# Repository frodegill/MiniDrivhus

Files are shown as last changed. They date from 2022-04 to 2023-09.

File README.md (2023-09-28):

## about project

Minidrivhus (english: indoor greenhouse) started as a dedicated system for pre-cultivating seeds indoors. It was based on ESP8266 and a custom shield that could support up to 3 soil sensors 3 water pumps and sensors for temperature, humidity and light intensity. There was also a relay for controlling an external grow light, and I've made custom PCBs for small and medium-sized indoor grow lights.  
With all this in place, I also started to make an outdoor greenhouse. When it was completed I expanded the project to also support outdoor greenhouse, which meant I had to add a relay to turn on and off a fan, sensors for outdoor temperature and humidity, a relay for operating a valve controlling water flow to an intermediate water reservoir, sensors for low and high level of water in this reservoir and voltage sensor for the solar panel charged 12V car battery that would power the whole system.  
Unfortunately, the first set of soil sensors did not handle humid/wet environment very well and the second (waterproof) soil sensor had a very limited value range, so I have now started redoing the whole system where the sensors are connected by RS-485 and the water pumps are controlled by a 16-channel multiplexer so one system can control up to 15 plants (having one channel act as an Off channel). To control this I needed more GPIO pins than the ESP8266 provided, so the new system will be based on an ESP32. Stay tuned for new and improved PCBs and source code!

## pictures

The original indoor greenhouse, ready for pre-cultivating seeds:  
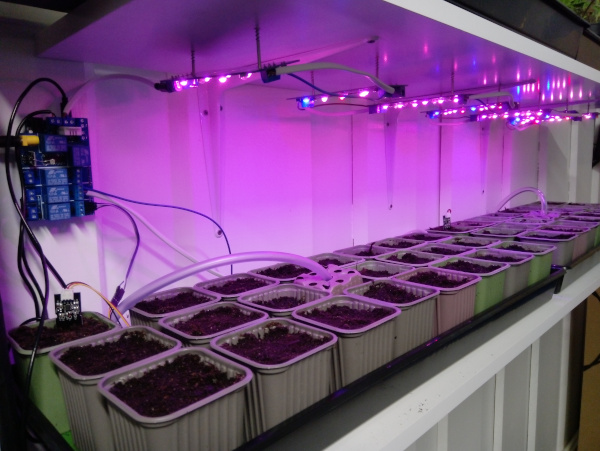
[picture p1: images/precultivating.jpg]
Minidrivhus setup


Setup for the outdoor greenhouse. 3 systems, each controlling 3 water pumps, for a total of 9 buckets for plants. There is also a small controller for the main water valve and a solar charge controller  
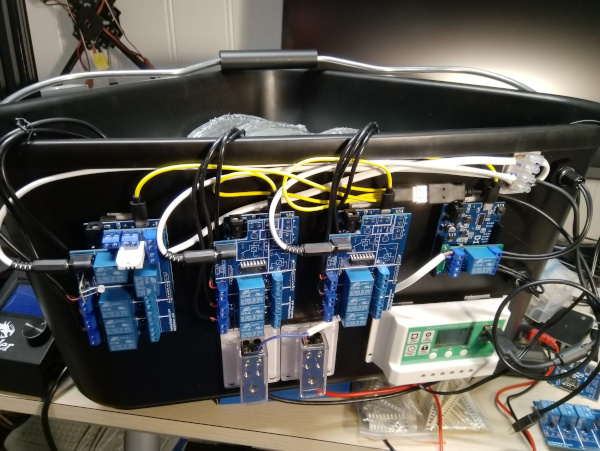
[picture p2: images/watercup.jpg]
watercup


I have 3 x 210 liter buckets for collecting rain water. The water is gravity-fed into an intermediate bucket in a corner of the greenhouse. All water pumps are located in this bucket. There are low- and high water level sensors that are used to control when a water valve is opened and water flows down from the 3 large buckets.  
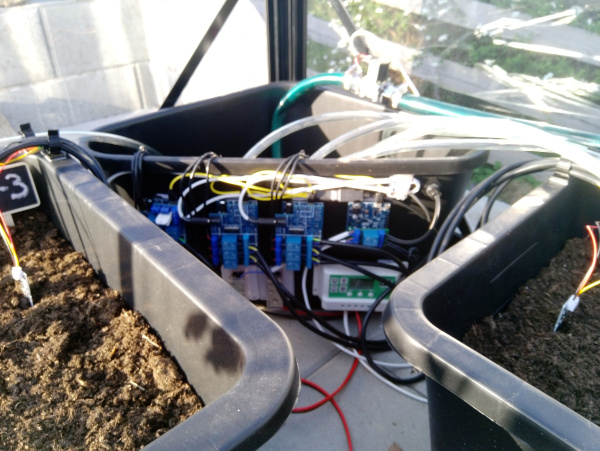
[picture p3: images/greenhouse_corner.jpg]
watercup in corner of greenhouse


A complete setup looks like this:  
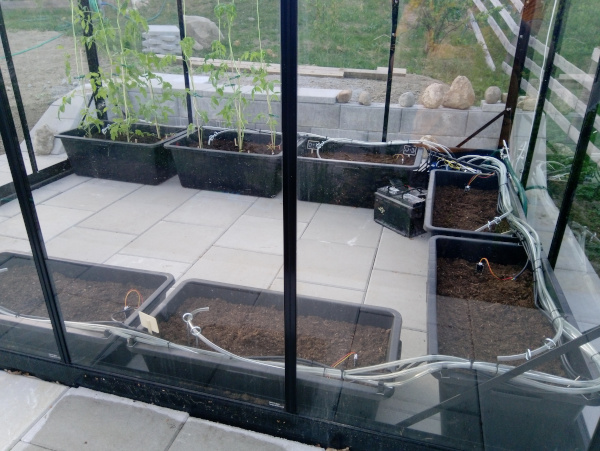
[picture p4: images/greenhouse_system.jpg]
greenhouse ready


..and after automatically watering plants all summer, it looks like this:  
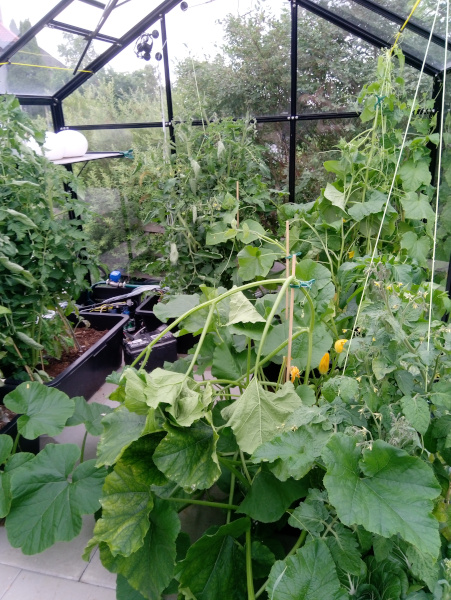
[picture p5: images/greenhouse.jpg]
greenhouse with plants


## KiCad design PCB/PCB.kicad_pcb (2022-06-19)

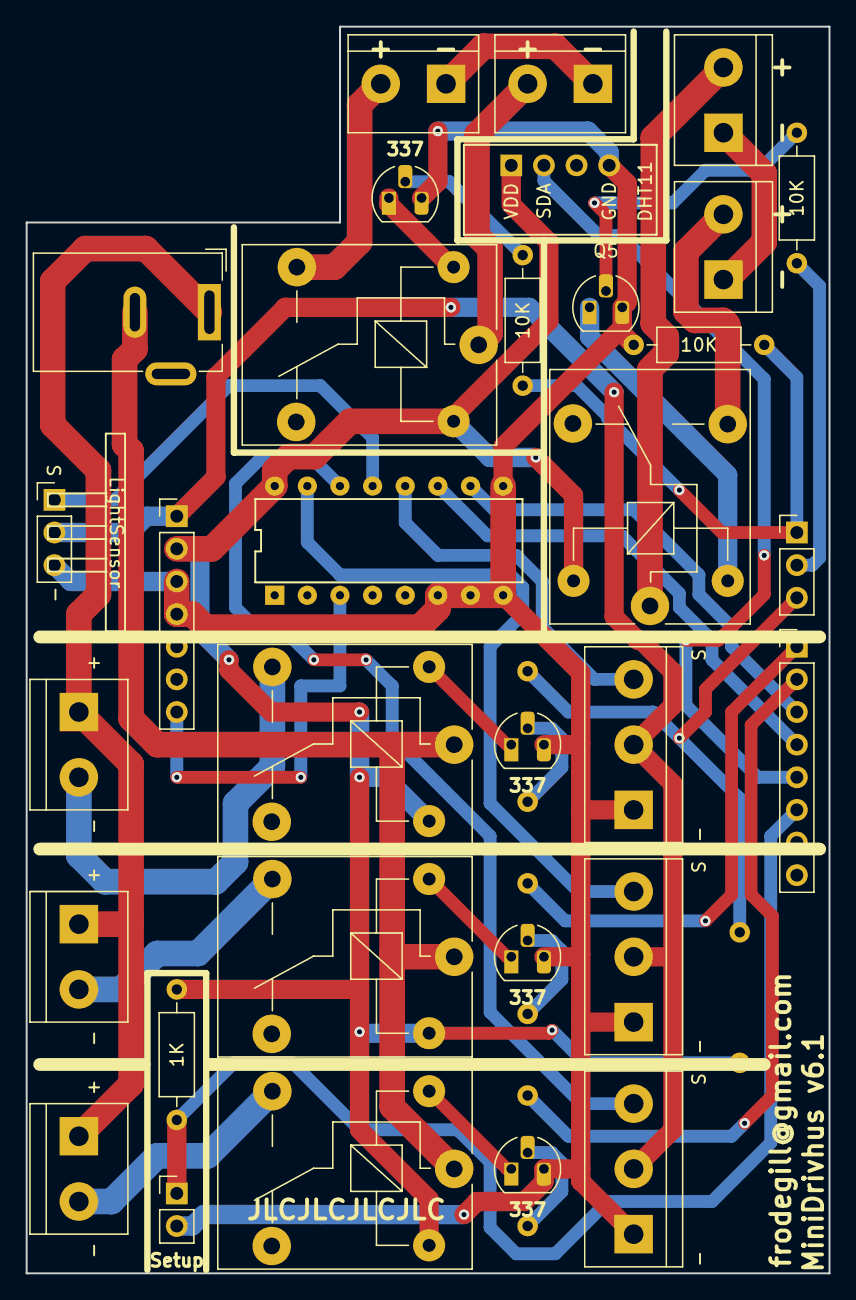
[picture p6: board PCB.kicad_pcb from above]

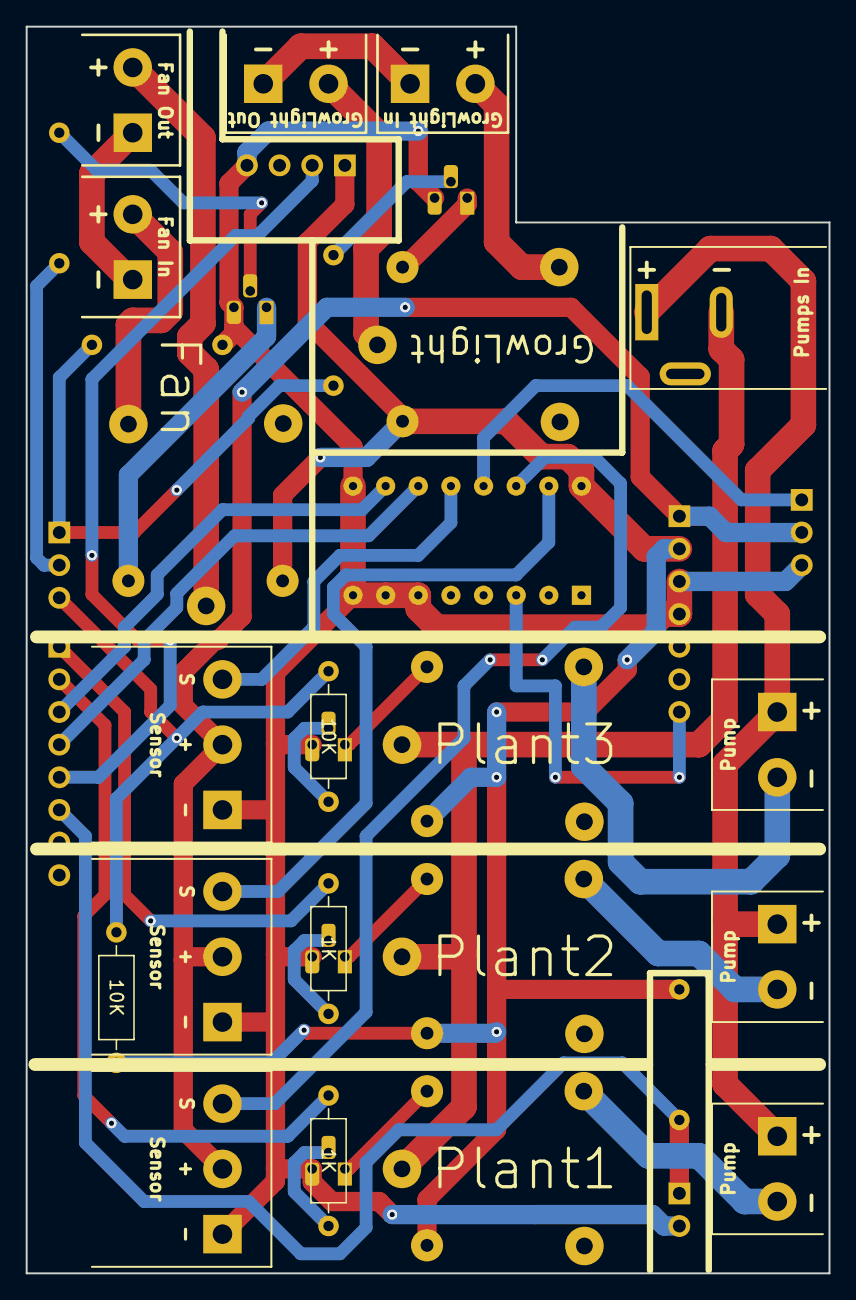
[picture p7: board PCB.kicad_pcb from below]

Board: 2 copper layers, 62.5 x 97.0 mm, 36 parts (4 on the bottom side), 38 nets.

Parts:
J1: PWR,A0; PinHeader_1x07_P2.54mm_Vertical
J2: Pump In; BarrelJack_Wuerth_6941xx301002
J3: LightSensor
J4: Pump1; TerminalBlock_bornier-2_P5.08mm
J5: Sensor1; TerminalBlock_bornier-3_P5.08mm
J6: GrowLight In; TerminalBlock_bornier-2_P5.08mm
J7: Pump2; TerminalBlock_bornier-2_P5.08mm
J8: Sensor2; TerminalBlock_bornier-3_P5.08mm
J9: Setup; PinHeader_1x02_P2.54mm_Vertical
J10: D8-D10; PinHeader_1x03_P2.54mm_Vertical
J11: D0-D7; PinHeader_1x08_P2.54mm_Vertical
J12: GrowLight Out; TerminalBlock_bornier-2_P5.08mm
J13: Pump3; TerminalBlock_bornier-2_P5.08mm
J14: Sensor3; TerminalBlock_bornier-3_P5.08mm
J15: Fan In; TerminalBlock_bornier-2_P5.08mm
J16: Fan Out; TerminalBlock_bornier-2_P5.08mm
K1: Relay1; Relay_SPDT_SANYOU_SRD_Series_Form_C
K2: RelayGrowlight; Relay_SPDT_SANYOU_SRD_Series_Form_C
K3: Relay2; Relay_SPDT_SANYOU_SRD_Series_Form_C
K4: Relay3; Relay_SPDT_SANYOU_SRD_Series_Form_C
K5: RelayFan; Relay_SPDT_SANYOU_SRD_Series_Form_C
Q1, Q2, Q3, Q4, Q5: BC337; TO-92_HandSolder
R1, R3, R4: 1K; R_Axial_DIN0207_L6.3mm_D2.5mm_P10.16mm_Horizontal
R2, R5, R6, R7, R8: 10K; R_Axial_DIN0207_L6.3mm_D2.5mm_P10.16mm_Horizontal
U1: DHT11; AM2302
U2: 74HC4051; 74HC4051N

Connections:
+3V3: J1.1, J3.2, J5.2, J8.2, J14.2
+5V: J1.2, K1.5, K2.5, K3.5, K4.5, K5.5, R4.1, R8.1, U1.1 (VCC), U2.16 (VCC)
GND: J1.3, J1.4, J3.3, J5.1, J8.1, J9.2, J14.1, Q1.3 (E), Q2.3 (E), Q3.3 (E), Q4.3 (E), Q5.3 (E), R7.1, U1.4 (GND), U2.6 (~E), U2.7 (VEE), U2.8 (GND), U2.9 (S2)
unnamed: J1.7, U2.3 (A)
unnamed: J2.2, K1.1, K3.1, K4.1
unnamed: J3.1, U2.13 (A0)
unnamed: J4.2, K1.3
unnamed: J5.3, U2.14 (A1)
unnamed: J6.2, K2.3
unnamed: J7.2, K3.3
unnamed: J8.3, U2.15 (A2)
unnamed: J10.1, R2.2, R7.2
unnamed: J10.2, R6.2
unnamed: J10.3, R5.2, R8.2
unnamed: J11.1, R3.2
unnamed: J11.2, R1.2
unnamed: J11.3, U2.10 (S1)
unnamed: J11.4, U2.11 (S0)
unnamed: J11.5, U1.2 (IO)
unnamed: J9.1, J11.6, R4.2
unnamed: J6.1, J12.1
unnamed: J12.2, K2.1
unnamed: J2.1, J4.1, J7.1, J13.1
unnamed: J13.2, K4.3
unnamed: J14.3, U2.12 (A3)
unnamed: J15.1, J16.1
unnamed: J15.2, K5.3
unnamed: J16.2, K5.1
unnamed: K1.2, Q1.1 (C)
unnamed: K2.2, Q2.1 (C)
unnamed: K3.2, Q3.1 (C)
unnamed: K4.2, Q4.1 (C)
unnamed: K5.2, Q5.1 (C)
unnamed: Q1.2 (B), R1.1
unnamed: Q2.2 (B), R2.1
unnamed: Q3.2 (B), R3.1
unnamed: Q4.2 (B), R5.1
unnamed: Q5.2 (B), R6.1

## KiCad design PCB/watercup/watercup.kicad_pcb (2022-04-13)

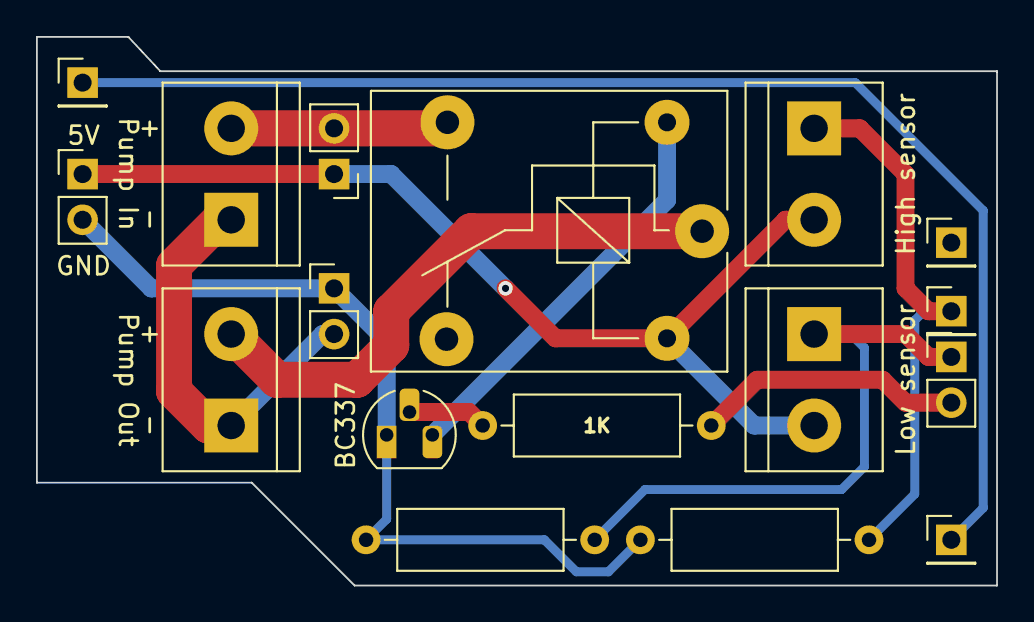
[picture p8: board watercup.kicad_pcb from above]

Board: 2 copper layers, 53.3 x 30.5 mm, 17 parts (0 on the bottom side), 11 nets.

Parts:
J1, J4, J5, J6: Conn_01x02_Male; TerminalBlock_bornier-2_P5.08mm
J2, J7, J9, J10: Conn_01x02_Male; PinHeader_1x02_P2.54mm_Vertical
J3, J8, J11, J12: Conn_01x01_Male; PinHeader_1x01_P2.54mm_Vertical
K1: SANYOU_SRD_Form_C; Relay_SPDT_SANYOU_SRD_Series_Form_C
Q1: BC337; TO-92_HandSolder
R1, R2: 4K7; R_Axial_DIN0309_L9.0mm_D3.2mm_P12.70mm_Horizontal
R4: 1K; R_Axial_DIN0309_L9.0mm_D3.2mm_P12.70mm_Horizontal

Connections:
+5V: J2.1, J4.2, J5.2, J9.1, K1.5
GND: J2.2, J10.1, Q1.1 (C), R1.1, R2.1
unnamed: J1.1, J6.1, J10.2
unnamed: J1.2, K1.1
unnamed: J3.1, J5.1, R1.2
unnamed: J4.1, J7.1, R2.2
unnamed: J6.2, J9.2, K1.3
unnamed: J7.2, R4.1
unnamed: J11.1, J12.1
unnamed: K1.2, Q1.3 (E)
unnamed: Q1.2 (B), R4.2

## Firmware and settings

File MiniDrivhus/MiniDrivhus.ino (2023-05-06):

#include "global.h"

#include "log.h"
#include "mqtt.h"
#include "ntp.h"
#include "settings.h"

#ifdef TESTING
# include "testing.h"
#else
# include <DHTesp.h>           // Library: DHT_sensor_library_for_ESPx
# include <Ticker.h>
# include <TimeLib.h>
#endif

/* PCB v4 for WeMos D1 R1

 MQTT paths:
 minidrivhus/<sensorid>/light
 minidrivhus/<sensorid>/temp
 minidrivhus/<sensorid>/humidity
 minidrivhus/<sensorid>/fan_on
 minidrivhus/<sensorid>/plant[0..(n-1)]/moisture
 minidrivhus/<sensorid>/plant[0..(n-1)]/watering_count
 minidrivhus/<sensorid>/plant[0..(n-1)]/water_now
 minidrivhus/<sensorid>/config/sec_between_reading
 minidrivhus/<sensorid>/config/growlight_minutes_pr_day                   [0 . 1440]
 minidrivhus/<sensorid>/config/fan_activate_temp                          [0.0 - 100.0]
 minidrivhus/<sensorid>/config/fan_activate_humid                         [0.0 - 100.0]
 minidrivhus/<sensorid>/config/plant[0..(n-1)]/enabled                    [0, 1]
 minidrivhus/<sensorid>/config/plant[0..(n-1)]/dry_value                  [wet - 100.0]
 minidrivhus/<sensorid>/config/plant[0..(n-1)]/wet_value                  [0.0 - dry]
 minidrivhus/<sensorid>/config/plant[0..(n-1)]/watering_duration_ms
 minidrivhus/<sensorid>/config/plant[0..(n-1)]/watering_grace_period_sec
 minidrivhus/<sensorid>/debug
 */

#define DHT_MODEL (DHTesp::AM2302)


static const unsigned int DELAY_BETWEEN_ACTIVE_SENSORS     = 25; //ms between activating sensors

enum State {
  SETUP_MODE,

  START,
  
  ACTIVATE_PLANT_SENSOR_1,
  READ_PLANT_SENSOR_1,
  ACTIVATE_PLANT_WATERING_1,
  DEACTIVATE_PLANT_WATERING_1,

  ACTIVATE_PLANT_SENSOR_2,
  READ_PLANT_SENSOR_2,
  ACTIVATE_PLANT_WATERING_2,
  DEACTIVATE_PLANT_WATERING_2,

  ACTIVATE_PLANT_SENSOR_3,
  READ_PLANT_SENSOR_3,
  ACTIVATE_PLANT_WATERING_3,
  DEACTIVATE_PLANT_WATERING_3,

  ACTIVATE_LIGHTSENSOR,
  READ_LIGHTSENSOR,

  READ_TEMPHUMIDSENSOR, //DHTxx cannot be read in interrupt, so this state is unused (reading is done in main loop)

  FINISHED
};


#if (LOG_LEVEL>LOG_LEVEL_NONE)
  Log g_log;
#endif // (LOG_LEVEL>LOG_LEVEL_NONE)
MQTT g_mqtt;
NTP g_ntp;
time_t local_time;
Settings g_settings;
DHTesp dht;

Ticker ticker;

volatile State state;
volatile bool should_read_temp_sensor;

volatile float plant_sensor_value[2][MAX_PLANT_COUNT];
volatile uint16_t plant_watering_count[2][MAX_PLANT_COUNT];
volatile unsigned long previous_plant_watering_time[MAX_PLANT_COUNT];
volatile bool plant_water_requested[MAX_PLANT_COUNT];
volatile bool plant_in_watering_cycle[MAX_PLANT_COUNT];
volatile uint16_t fan_value[2];
volatile float lightsensor_value[2];
float tempsensor_value[2];
float humiditysensor_value[2];

bool growlight_lit;


byte whichOf(const volatile State& state, const State& /*o1_default*/, const State& o2, const State& o3)
{
  if (state==o2) return 1;
  else if (state==o3) return 2;
  else return 0;
}

State nextState(byte plant, const State& o1_default, const State& o2, const State& o3)
{
  if (plant==1) return o2;
  else if (plant==2) return o3;
  else return o1_default;
}

void selectAnalogAddr(byte addr)
{
  digitalWrite(O_ANALOG_ADDR_S0, (addr&0x01)==0?LOW:HIGH);
  digitalWrite(O_ANALOG_ADDR_S1, (addr&0x02)==0?LOW:HIGH);
}

void onTick()
{
  switch(state)
  {
    case START:
      {
        ticker.attach_ms(DELAY_BETWEEN_ACTIVE_SENSORS, onTick);
        state = ACTIVATE_PLANT_SENSOR_1;
        break;
      }

    case ACTIVATE_PLANT_SENSOR_1:
    case ACTIVATE_PLANT_SENSOR_2:
    case ACTIVATE_PLANT_SENSOR_3:
      {
        byte plant = whichOf(state, ACTIVATE_PLANT_SENSOR_1, ACTIVATE_PLANT_SENSOR_2, ACTIVATE_PLANT_SENSOR_3);
        selectAnalogAddr(ANALOG_PLANT_SENSOR_ADDR[plant]);
        ticker.attach_ms(DELAY_BETWEEN_ACTIVE_SENSORS, onTick);
        state = nextState(plant, READ_PLANT_SENSOR_1, READ_PLANT_SENSOR_2, READ_PLANT_SENSOR_3);
        break;
      }

    case READ_PLANT_SENSOR_1:
    case READ_PLANT_SENSOR_2:
    case READ_PLANT_SENSOR_3:
      {
        byte plant = whichOf(state, READ_PLANT_SENSOR_1, READ_PLANT_SENSOR_2, READ_PLANT_SENSOR_3);
        plant_sensor_value[CURRENT][plant] = max(0.0f, min(100.0f, 100.0f*static_cast<float>(analogRead(A0))/static_cast<float>(MAX_ANALOG_VALUE)));
        LOG_DEBUG((String("onTick - read sensor ")+String((int)plant)+String(", got ")+String((int)plant_sensor_value[CURRENT][plant])).c_str());
        ticker.attach_ms(DELAY_BETWEEN_ACTIVE_SENSORS, onTick);
        state = nextState(plant, ACTIVATE_PLANT_WATERING_1, ACTIVATE_PLANT_WATERING_2, ACTIVATE_PLANT_WATERING_3);
        break;
      }

    case ACTIVATE_PLANT_WATERING_1:
    case ACTIVATE_PLANT_WATERING_2:
    case ACTIVATE_PLANT_WATERING_3:
      {
        byte plant = whichOf(state, ACTIVATE_PLANT_WATERING_1, ACTIVATE_PLANT_WATERING_2, ACTIVATE_PLANT_WATERING_3);

        if (g_settings.conf_plant_enabled[plant])
        {
          if (plant_in_watering_cycle[plant] && plant_sensor_value[CURRENT][plant]<=g_settings.conf_wet_value[plant])
          {
            plant_in_watering_cycle[plant] = false;
            LOG_INFO((String("onTick - plant")+String((int)plant)+String(" exiting watering cycle: ")+String(plant_sensor_value[CURRENT][plant], 4)+String(", ")+String(g_settings.conf_wet_value[plant], 4) +String("-") + String(g_settings.conf_dry_value[plant], 4)).c_str());
          }
          else if (!plant_in_watering_cycle[plant] && plant_sensor_value[CURRENT][plant]>=g_settings.conf_dry_value[plant])
          {
            plant_in_watering_cycle[plant] = true;
            LOG_INFO((String("onTick - plant")+String((int)plant)+String(" entering watering cycle: ")+String(plant_sensor_value[CURRENT][plant], 4)+String(", ")+String(g_settings.conf_wet_value[plant], 4) +String("-") + String(g_settings.conf_dry_value[plant], 4)).c_str());
          }
        }
        
        if (g_settings.conf_plant_enabled[plant] && (plant_water_requested[plant] || plant_in_watering_cycle[plant]))
        {
          unsigned long current_sec = millis()/1000;
          if (current_sec < previous_plant_watering_time[plant]) //Wrapped. Happens every ~50 days
          {
            previous_plant_watering_time[plant] = current_sec;
          }
          
          if (plant_water_requested[plant] || (previous_plant_watering_time[plant]==0 || (previous_plant_watering_time[plant]+g_settings.conf_watering_grace_period_sec[plant] < current_sec)))
          {
            LOG_DEBUG((String("onTick - activate watering ")+String((int)plant) + ": " + String(plant_sensor_value[CURRENT][plant], 4)).c_str());
            digitalWrite(O_PLANT_WATERING_PINS[plant], HIGH);
            plant_watering_count[CURRENT][plant]++;
            previous_plant_watering_time[plant] = current_sec;
            plant_water_requested[plant] = false;
            ticker.attach_ms(g_settings.conf_watering_duration_ms[plant], onTick);
            state = nextState(plant, DEACTIVATE_PLANT_WATERING_1, DEACTIVATE_PLANT_WATERING_2, DEACTIVATE_PLANT_WATERING_3);
          }
          else
          {
            ticker.attach_ms(DELAY_BETWEEN_ACTIVE_SENSORS, onTick);
            state = nextState(plant, ACTIVATE_PLANT_SENSOR_2, ACTIVATE_PLANT_SENSOR_3, ACTIVATE_LIGHTSENSOR);
          }
        }
        else
        {
          ticker.attach_ms(DELAY_BETWEEN_ACTIVE_SENSORS, onTick);
          state = nextState(plant, ACTIVATE_PLANT_SENSOR_2, ACTIVATE_PLANT_SENSOR_3, ACTIVATE_LIGHTSENSOR);
        }

        break;
      }

    case DEACTIVATE_PLANT_WATERING_1:
    case DEACTIVATE_PLANT_WATERING_2:
    case DEACTIVATE_PLANT_WATERING_3:
      {
        byte plant = whichOf(state, DEACTIVATE_PLANT_WATERING_1, DEACTIVATE_PLANT_WATERING_2, DEACTIVATE_PLANT_WATERING_3);
        digitalWrite(O_PLANT_WATERING_PINS[plant], LOW);
        ticker.attach_ms(DELAY_BETWEEN_ACTIVE_SENSORS, onTick);
        state = nextState(plant, ACTIVATE_PLANT_SENSOR_2, ACTIVATE_PLANT_SENSOR_3, ACTIVATE_LIGHTSENSOR);
        break;
      }

      case ACTIVATE_LIGHTSENSOR:
      {
        selectAnalogAddr(ANALOG_LIGHT_SENSOR_ADDR);
        ticker.attach_ms(DELAY_BETWEEN_ACTIVE_SENSORS, onTick);
        state = READ_LIGHTSENSOR;
        break;
      }
      
      case READ_LIGHTSENSOR:
      {
        int value = max(0, min(static_cast<int>(MAX_ANALOG_VALUE), analogRead(A0)));
        lightsensor_value[CURRENT] = 100.0f - 100.0f*static_cast<float>(value)/static_cast<float>(MAX_ANALOG_VALUE);
        LOG_DEBUG((String("onTick - light sensor. Read value ")+String((int)lightsensor_value[CURRENT])).c_str());
        ticker.attach_ms(DELAY_BETWEEN_ACTIVE_SENSORS, onTick);
        state = READ_TEMPHUMIDSENSOR;
        break;
      }

    case READ_TEMPHUMIDSENSOR:
      {
        //DHTxx cannot be read in interrupt, so this state is unused (reading is done in main loop)
        should_read_temp_sensor = true;
        ticker.attach_ms(DELAY_BETWEEN_ACTIVE_SENSORS, onTick);
        state = FINISHED;
        break;
      }

    case FINISHED:
      {
        selectAnalogAddr(0);
        ticker.attach_ms(g_settings.conf_sec_between_reading*1000, onTick);
        state = START;
        break;
      }
    
    default:
      {
        LOG_ERROR("Unknown state");
      }
  }
}

void updateValue(const String& topic, float new_value, volatile float& old_value)
{
  if (new_value != old_value)
  {
    g_mqtt.publishMQTTValue(topic, String(new_value));
    old_value = new_value;
  }
}

void updateValue(const String& topic, uint16_t new_value, volatile uint16_t& old_value)
{
  if (new_value != old_value)
  {
    g_mqtt.publishMQTTValue(topic, String(new_value));
    old_value = new_value;
  }
}

void setup()
{
  Serial.end();
  Serial1.end();
  delay(1000);

#if (LOG_LEVEL>LOG_LEVEL_NONE)
  g_log.enable();
  LOG_INFO("start setup");
#endif // (LOG_LEVEL>LOG_LEVEL_NONE)

  g_settings.enable();
  
  pinMode(I_SETUP_MODE_PIN, INPUT);
  delay(100);

  if (LOW == digitalRead(I_SETUP_MODE_PIN))
  {
    LOG_INFO("Mode = SETUP");

    state = SETUP_MODE;
    g_settings.activateSetupAP();
  }
  else
  {
    LOG_INFO("Mode = NORMAL");

    pinMode(I_TEMPHUMIDSENSOR_PIN, OUTPUT); //DHT handles this pin itself, but it should be OUTPUT before setup
    dht.setup(I_TEMPHUMIDSENSOR_PIN, DHT_MODEL);

    //Prepare pins
    byte i;
    for (i=0; i<MAX_PLANT_COUNT; i++)
    {
      pinMode(O_PLANT_WATERING_PINS[i], OUTPUT);
    }
    pinMode(O_FAN_RELAY_ACTIVATE_PIN, OUTPUT);
    pinMode(O_LIGHT_RELAY_ACTIVATE_PIN, OUTPUT);
    pinMode(O_ANALOG_ADDR_S0, OUTPUT);
    pinMode(O_ANALOG_ADDR_S1, OUTPUT);
    pinMode(A0, INPUT);

    //Set output pins
    for (i=0; i<MAX_PLANT_COUNT; i++)
    {
      digitalWrite(O_PLANT_WATERING_PINS[i], LOW);
    }
    digitalWrite(O_FAN_RELAY_ACTIVATE_PIN, LOW);
    digitalWrite(O_LIGHT_RELAY_ACTIVATE_PIN, LOW);
    selectAnalogAddr(0);

    for (i=0; i<MAX_PLANT_COUNT; i++)
    {
      plant_sensor_value[CURRENT][i] = plant_sensor_value[OLD][i] = 0.0f;
      plant_watering_count[CURRENT][i] = plant_watering_count[OLD][i] = 0;
      previous_plant_watering_time[i] = 0;
      plant_water_requested[i] = false;
      plant_in_watering_cycle[i] = false;
    }
    fan_value[CURRENT] = fan_value[OLD] = 0;
    lightsensor_value[CURRENT] = lightsensor_value[OLD] = 0.0f;
    tempsensor_value[CURRENT] = tempsensor_value[OLD] = 0.0f;
    humiditysensor_value[CURRENT] = humiditysensor_value[OLD] = 0.0f;
    should_read_temp_sensor = false;

    if (!g_settings.activateWifi())
    {
      // reset?
    }

    //Make some noise to say we're alive!
    for (i=0; i<4; i++)
    {
      delay(200);
      digitalWrite(O_LIGHT_RELAY_ACTIVATE_PIN, HIGH);
      delay(200);
      digitalWrite(O_LIGHT_RELAY_ACTIVATE_PIN, LOW);
    }
    growlight_lit = false;
    
    state = START;
    LOG_DEBUG("state=START");
    onTick();
  }
}

void loop()
{
  g_settings.processNetwork(state == SETUP_MODE);

  if (state == SETUP_MODE) {
    delay(100);
  }
  else
  {
    delay(max(1000, dht.getMinimumSamplingPeriod()));
    if (should_read_temp_sensor)
    {
      TempAndHumidity temp_and_humidity = dht.getTempAndHumidity();
      if (dht.getStatus() == DHTesp::ERROR_NONE)
      {
        should_read_temp_sensor = false;
        tempsensor_value[CURRENT] = temp_and_humidity.temperature;
        humiditysensor_value[CURRENT] = temp_and_humidity.humidity;

        updateValue(F("temp"), tempsensor_value[CURRENT], tempsensor_value[OLD]);
        updateValue(F("humidity"), humiditysensor_value[CURRENT], humiditysensor_value[OLD]);

        fan_value[CURRENT] = fan_value[OLD];
        if ((tempsensor_value[CURRENT]>=g_settings.conf_fan_activate_temp_value*1.005) || (humiditysensor_value[CURRENT]>=g_settings.conf_fan_activate_humid_value*1.005))
        {
          fan_value[CURRENT] = 1;
        }
        if ((tempsensor_value[CURRENT]<=g_settings.conf_fan_activate_temp_value*0.995) || (humiditysensor_value[CURRENT]<=g_settings.conf_fan_activate_humid_value*0.995))
        {
          fan_value[CURRENT] = 0;
        }

        if (fan_value[CURRENT] != fan_value[OLD])
        {
          digitalWrite(O_FAN_RELAY_ACTIVATE_PIN, fan_value[CURRENT]==0 ? LOW : HIGH);
          updateValue(F("fan_on"), fan_value[CURRENT], fan_value[OLD]);
        }
      }
      else
      {
        LOG_ERROR((String("reading temp and humidity failed with error ")+String((int)dht.getStatus())).c_str());
      }

      updateValue(F("light"), lightsensor_value[CURRENT], lightsensor_value[OLD]);
    }
  
    byte plant;
    for (plant=0; plant<MAX_PLANT_COUNT; plant++)
    {
      if (!g_settings.conf_plant_enabled[plant])
        continue;
        
      String plant_path = F("plant");
      plant_path += String(plant);
  
      updateValue(plant_path+F("/moisture"), plant_sensor_value[CURRENT][plant], plant_sensor_value[OLD][plant]);
  
      updateValue(plant_path+F("/watering_count"), plant_watering_count[CURRENT][plant], plant_watering_count[OLD][plant]);
      plant_watering_count[CURRENT][plant] = plant_watering_count[OLD][plant] = 0;
    }

    if (g_ntp.getLocalTime(local_time)) {
      short current_minute = hour(local_time)*60 + minute(local_time);
      short turn_on = 12*60 - g_settings.conf_growlight_minutes_pr_day/2;
      short turn_off = 12*60 + g_settings.conf_growlight_minutes_pr_day/2;
      if (growlight_lit && (current_minute<turn_on || current_minute>=turn_off)) {
        digitalWrite(O_LIGHT_RELAY_ACTIVATE_PIN, LOW);
        growlight_lit = false;
        LOG_INFO("Shutting off growlight");
      } else if (!growlight_lit && (current_minute>=turn_on && current_minute<turn_off)) {
        digitalWrite(O_LIGHT_RELAY_ACTIVATE_PIN, HIGH);
        growlight_lit = true;
        LOG_INFO("Turning on growlight");
      }
    } else {
      LOG_INFO("Time is unknown");
    }
  }
}

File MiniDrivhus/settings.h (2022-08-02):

#ifndef _SETTINGS_H_
#define _SETTINGS_H_

#ifdef TESTING
# include "testing.h"
#else
# include <DNSServer.h>
# include <EEPROM.h>
# include <ESP8266WebServer.h>
#endif

#include "global.h"


void handleNotFound();
void handleSetupRoot();

class Settings
{
public:
  static constexpr const char* SETUP_SSID = "sensor-setup";
  static constexpr byte  EEPROM_INITIALIZED_MARKER = 0xF2; //Just a magic number. CHange when EEPROM data format is incompatibly changed

  static constexpr byte MAX_SSID_LENGTH            = 32;
  static constexpr byte MAX_PASSWORD_LENGTH        = 64;
  static constexpr byte MAX_MQTT_SERVERNAME_LENGTH = 64;
  static constexpr byte MAX_MQTT_SERVERPORT_LENGTH =  5;
  static constexpr byte MAX_MQTT_SENSORID_LENGTH   = 32;
  static constexpr byte MAX_MQTT_USERNAME_LENGTH   = 32;
  static constexpr byte MAX_MQTT_PASSWORD_LENGTH   = 32;

  static constexpr uint16_t MQTT_DEFAULT_PORT = 1883;

  static constexpr unsigned int DEFAULT_CONF_SEC_BETWEEN_READING       = 5;      //secoonds min. time between sensor activation
  static constexpr float        DEFAULT_CONF_DRY_VALUE                 = 54.0f;  //[wet - 100.0]
  static constexpr float        DEFAULT_CONF_WET_VALUE                 = 46.0f;  //[0.0 - dry]
  static constexpr float        DEFAULT_CONF_FAN_ACTIVATE_TEMP_VALUE   = 40.0f;  //[0.0 - 100.0]
  static constexpr float        DEFAULT_CONF_FAN_ACTIVATE_HUMID_VALUE  = 98.0f;  //[0.0 - 100.0]
  static constexpr unsigned int DEFAULT_CONF_WATERING_DURATION_MS      = 3*1000; //ms to keep watering
  static constexpr unsigned int DEFAULT_CONF_WATERING_GRACE_PERIOD_SEC = 20*60;  //sec min. time between watering
  static constexpr unsigned int DEFAULT_CONF_GROWLIGHT_MINUTES_PR_DAY  = 16*60;  //minutes with growlight lit pr day
  static constexpr const char*  DEFAULT_SENSORID = "/MiniDrivhus/Sensor1/";
  static constexpr byte         DEFAULT_CONF_PLANT_ENABLED             = 1;

public:
  Settings();
  void enable();
  void readPersistentString(char* s, int max_length, int& adr);
  void readPersistentByte(uint8_t& b, int& adr);
  void readPersistentParams();
  void writePersistentString(const char* s, size_t max_length, int& adr);
  void writePersistentByte(uint8_t b, int& adr);
  void writePersistentParams(const char* ssid, const char* password);
  void handleNotFound();
  void handleSetupRoot();
  void activateSetupAP();
  bool activateWifi();
  void processNetwork(bool setup_mode);

public:
  std::shared_ptr<ESP8266WebServer> server;

  //For SETUP_SSID AP
  DNSServer dnsServer;
  static constexpr const byte DNS_PORT = 53;
  std::shared_ptr<IPAddress> apIP;

  char ssid_param[MAX_SSID_LENGTH+1];
  char password_param[MAX_PASSWORD_LENGTH+1];
  char mqtt_servername_param[MAX_MQTT_SERVERNAME_LENGTH+1];
  uint16_t mqtt_serverport_param = MQTT_DEFAULT_PORT;
  char mqtt_sensorid_param[MAX_MQTT_SENSORID_LENGTH+1];
  char mqtt_username_param[MAX_MQTT_USERNAME_LENGTH+1];
  char mqtt_password_param[MAX_MQTT_PASSWORD_LENGTH+1];

  unsigned int conf_sec_between_reading;
  short conf_growlight_minutes_pr_day;
  byte conf_plant_enabled[MAX_PLANT_COUNT];
  float conf_dry_value[MAX_PLANT_COUNT];
  float conf_wet_value[MAX_PLANT_COUNT];
  float conf_fan_activate_temp_value;
  float conf_fan_activate_humid_value;
  unsigned int conf_watering_duration_ms[MAX_PLANT_COUNT];
  unsigned int conf_watering_grace_period_sec[MAX_PLANT_COUNT];
};

#endif // _SETTINGS_H_

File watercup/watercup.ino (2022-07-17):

#include "global.h"

# include <TimeLib.h>

#include "steppermotor.h"
#include "mqtt.h"
#include "ntp.h"
#include "settings.h"

/*
 MQTT paths:
 watercup/<sensorid>/valve_open
 */


enum State {
  SETUP_MODE,
  NORMAL
};
volatile State state;

StepperMotor g_steppermotor;
MQTT g_mqtt;
NTP g_ntp;
time_t local_time;
Settings g_settings;

volatile unsigned long failsafeDelay;

volatile bool valve_open;
volatile bool valve_changed_state;


void setup() {
  Serial.begin(9600);

  g_steppermotor.initialize();
  g_settings.enable();
  
  pinMode(I_SETUP_MODE_PIN, INPUT);
  delay(100);

  if (false && (LOW == digitalRead(I_SETUP_MODE_PIN)))
  {
    Serial.println("Setup");
    state = SETUP_MODE;
    g_settings.activateSetupAP();
  }
  else
  {
    Serial.println("Normal");
    state = NORMAL;

    pinMode(O_TRIGGER_PIN, OUTPUT);
    digitalWrite(O_TRIGGER_PIN, LOW);
    failsafeDelay = LONG_DELAY;
    
    pinMode(I_LOW_SENSOR_PIN, INPUT);
    pinMode(I_HIGH_SENSOR_PIN, INPUT);

    attachInterrupt(digitalPinToInterrupt(I_LOW_SENSOR_PIN), updateFlowStatus, CHANGE);
    attachInterrupt(digitalPinToInterrupt(I_HIGH_SENSOR_PIN), updateFlowStatus, CHANGE);

    if (!g_settings.activateWifi())
    {
      // reset?
    }

    valve_open = false;
    valve_changed_state = true;
    
    updateFlowStatus();
  }
}

void loop() {
  g_settings.processNetwork(state == SETUP_MODE);

  if (state == SETUP_MODE) {
    delay(100);
  }
  else
  {
    delay(failsafeDelay);
    updateFlowStatus();

    if (valve_changed_state) // Publishing to MQTT cannot be done in interrupt
    {
      g_mqtt.publishMQTTValue(F("valve_open"), String(valve_open ? "1" : "0"));
      valve_changed_state = false;
    }

    if (g_ntp.getLocalTime(local_time)) {
      short current_minute = hour(local_time)*60 + minute(local_time); // 0 - 1440
    } else {
      // Time is unknown
    }

    g_steppermotor.step();
  }
}

ICACHE_RAM_ATTR void updateFlowStatus()
{
  int low_status = digitalRead(I_LOW_SENSOR_PIN);
  int high_status = digitalRead(I_HIGH_SENSOR_PIN);
  int trigger_status = digitalRead(O_TRIGGER_PIN);
  if (trigger_status==LOW && low_status==LOW && high_status!=HIGH /*fail safe*/)
  {
    digitalWrite(O_TRIGGER_PIN, HIGH);
    failsafeDelay = SHORT_DELAY;
    valve_open = true;
    valve_changed_state = true;
  }
  
  if (trigger_status==HIGH && high_status==HIGH)
  {
    digitalWrite(O_TRIGGER_PIN, LOW);
    failsafeDelay = LONG_DELAY;
    valve_open = false;
    valve_changed_state = true;
  }
}

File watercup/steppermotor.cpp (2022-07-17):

#include "steppermotor.h"

#include "global.h"


void StepperMotor::initialize()
{
  pinMode(O_STEPPERMOTOR_CS_PIN, OUTPUT);
  pinMode(O_STEPPERMOTOR_DIR_PIN, OUTPUT);
  pinMode(O_STEPPERMOTOR_ENABLE_PIN, OUTPUT);
  digitalWrite(O_STEPPERMOTOR_ENABLE_PIN, LOW);
  digitalWrite(O_STEPPERMOTOR_CS_PIN, LOW);
  m_steps = 0;
}

void StepperMotor::addStep(int steps, bool reverse)
{
  m_steps += (reverse ? -steps : steps);
}

void StepperMotor::step()
{
  if (m_steps == 0)
    return;

  digitalWrite(O_STEPPERMOTOR_ENABLE_PIN, HIGH);
  digitalWrite(O_STEPPERMOTOR_DIR_PIN, m_steps < 0 ? LOW : HIGH);
  delayMicroseconds(25);
  digitalWrite(O_STEPPERMOTOR_CS_PIN, HIGH);
  delayMicroseconds(STEPPERMOTOR_SPEED);
  digitalWrite(O_STEPPERMOTOR_CS_PIN, LOW);

  m_steps -= (m_steps < 0 ? -1 : 1);
  if (m_steps == 0)
  {
    digitalWrite(O_STEPPERMOTOR_ENABLE_PIN, LOW);
  }
}

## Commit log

2018-03-25 Invert water-value. 0.0 is dry, 100.0 is wet
    [MiniDrivhus.ino]
2018-03-27 Added fritzing
    [MiniDrivhus.fzz]
2018-04-01 Added KiCad PCB
    [MiniDrivhus.kicad_pcb]
2018-04-02 Added setup-mode (pull D7 to GND before boot), including some really ugly string parsing
2019-01-05 Prepare for new PCB, adding mqtt support
2019-01-25 Quite a few bug-fixes and features...
    [MiniDrivhus.ino]
2019-01-26 Fixed password persist and MQTT values for temp/humidity
    [MiniDrivhus.ino]
2019-01-26 Light worked on first attempt. Use actual (and correct) value :-)
    [MiniDrivhus.ino]
2019-02-23 New and improved PCB
    [MiniDrivhus.kicad_pcb, MiniDrivhusV2.kicad_pcb]
2019-04-25 Adapted for WeMos D1 R32 board
2019-05-11 PCB for the Wemos D1 R32
    [MiniDrivhusV3.kicad_pcb]
2019-05-11 Implemented valve grace period, and made ESP32 network handling more robust
2020-02-02 Preparing for MiniDrivhus v4
    [MiniDrivhusV2.kicad_pcb, MiniDrivhusV3.kicad_pcb, PCB.kicad_pcb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]
2020-02-13 Some renaming. Completed mqtt updates and fixed some code smell
    [MiniDrivhus.ino, global.h, mqtt.cpp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]
2020-04-10 Moisture values are now percent, fixed mqtt subscribe topics typo and cleaned up debug message calls
    [MiniDrivhus.ino, mqtt.cpp, settings.h]
2020-04-20 Kicad-files for MivinDrivhus_v5
    [PCB.kicad_pcb, PCB.sch]
2020-04-30 PCB v5.1
    [PCB.kicad_pcb, PCB.sch]
2022-04-11 Misc fixes that has started collecting dust locally
    [MiniDrivhus.ino, global.h, mqtt.cpp]
2022-04-13 Added support for the fan relay
    [PCB.kicad_pcb, PCB.sch]
2022-04-13 Added ino for the watercup arduino controller
2022-04-13 Added watercup controller PCB files
    [watercup.kicad_pcb, watercup.sch]
2022-06-19 Added fan support to minidrivhus
    [PCB.kicad_pcb]
2022-07-17 Added support for stepper motor
2023-05-06 Don't use a hard limit for turning fan on/off
